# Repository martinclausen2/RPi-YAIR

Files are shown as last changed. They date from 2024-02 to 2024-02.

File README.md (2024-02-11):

# RPi-YAIR
Raspberry Pi YAIR (Yet Another Internet Radio)

Diverted from [Raspberry Pi YAIR - Yet Another Internet Radio](https://www.mikrocontroller.net/articles/Raspberry_Pi_YAIR_(Yet_Another_Internet_Radio) )

German parts to be translated later. Details on one particular hardware setup to be found under articel cited above.

### Einleitung

Ja, es gibt sie: Internetradios. Zum Kaufen. Zum Selbst bauen. Aus Routern. Aus dem Raspberry Pi. Aber schlussendlich gefiel mir keines so gut, dass es mich vom Selbstbau abgehalten hätte ...
### Features für den Nutzer

* Intuitive Bedienung über zwei Drehencoder mit Tastfunktion
  * Dynamische Schrittweitenanpassung für die schnelle und genaue Einstellung der Lautstärke und Sender
* Fernbedienbar via IR-Fernbedieung oder Netzwerk / WLAN via Smartphone
* Sehr niedriger Standby-Stromverbrauch
* Lesen der Musik via Netzwerk oder empfang via BT

### Hardware Setup

* Basis Raspberry Pi Zero (nur headless) oder besser, 512MB, WLAN und BT
* I2S Audio DAC connection please see [External-Non-USB-Audio-DAC-ES9023,-PCM5102,-etc.](https://github.com/MiczFlor/RPi-Jukebox-RFID/wiki/External-Non-USB-Audio-DAC-ES9023,-PCM5102,-etc.)
* Microcontroller connnection please see [Raspberry Pi YAIR - Yet Another Internet Radio](https://www.mikrocontroller.net/articles/Raspberry_Pi_YAIR_(Yet_Another_Internet_Radio) )

## MCU

Die Software besteht aus folgenden Teilen:

* Hauptschleife
  * Setzt Zustände der State-Machines in Befehle, die über den UART gesendet werden, um
  * Steuert die Stromversorgung von Raspberry Pi, Monitor und Audio-Verstärker

* Interrupt-Routinen
  * RC5 Decoder, ausgelöst durch Timer 0 bei 4,5kHz, jeden 9. Aufruf wird auch der Drehencoder ausgewertet
  * Einlesen der Tasten, ausgelöst durch Timer aus RTC der MCU bei 10Hz

* Initialisierung der MCU
  * Core Funktionen, hauptsächliche Stromsparfunktionen
  * I/O Pins
  * Interne RTC als 10Hz Taktgeber: 6*10^6/4/128/10
  * UART: 57600 Bit/s Mode 1
  * Watchdog wird abgeschaltet
  * Interrupts freischalten

* Auswertung Drehencoder

* RC5 Decoder

Der RC5 Decoder beruht auf einer State-Machine, die schrittweise die einzelnen Bits erkennt und dann in Adresse und Daten zerlegt. Nach der Erkennung eines kompletten Kommandos wird steht rCounter auf dem Wert 12 und das Hauptprogramm beginnt mit der Decodierung (Aufruf "DecodeRemote()").

Die Software kann per #define in Quellcode für LPC922 oder LPC93X kompiliert werden. Die zusätzlichen Funktionsblöcke der LPC93X werden nicht verwendet. Als Kompiler ist SDCC zu verwenden.

Bei Bedarf könnte ich MCUs programmieren. Alternativ ist der Code sicher leicht auf einen AVR, STM32, oder ... zu portieren. 

## Raspberry Pi Setup

### Step by Step Instructions

Please follow the follwoing steps to steup the raspberry pi

* deploy raspberry pi os bookworm on sdcard
* setup the configuration 'sudo raspi-config'
  * setup system options
    * WLAN
    * Hostname
  * Interface
    * SSH
    * Serail Port - enable serial port, but not (!) console
  * Localisation Options
    * Timezone
    * Keyboard
    * WLAN Country
  * Advanced Options
    * Expand Filesystem
* update repos `sudo apt-get update`
* update software `sudo apt-get dist-upgrade`
* install software `sudo apt-get install mpd mpc wakeonlan git`
* Reboot Rpi
* Adjust configuration files from RPi folder and changes dummy credentials, consider to modifiy the following files on your traget system in case your installation has other specifics.  
  * `/boot/firmware/cmdline.txt`
    * remove `console=tty1`
  * `/boot/firmware/config.txt`
    * remove `dtparam=audio=on` by addin a hash in fromt of the line
    * add `dtoverlay=hifiberry-dac`
  * If you decide to adjust the start volue, you need to do it in `receiver.c`, complie again, and in `startmpd.sh`
* Copy adjusted configuration files to RPi
* Install BT audio receiver
  * `git clone https://github.com/nicokaiser/rpi-audio-receiver.git`
  * `cd rpi-audio-receiver`
  * Choose the features as needed when running `./install.sh`
* create folder to mount music folder from NAS
  * `mkdir /media/music`
  * `chmod 555 /media/music`
* Make playlist folder accessable `sudo chmod 777 /var/lib/mpd/playlists`
  * Deploy there at least `radio.m3u`, this is used for playback at startup (entry 4)
* stop automated concole activation
  * details may depend on your sprecific RPi model and configuration
	* use `systemctl status` to check for any serial-getty services running and deactivte them using stop, disable, mask
  * `sudo systemctl stop serial-getty@ttyAMA0.service`
  * `sudo systemctl disable serial-getty@ttyAMA0.service`
  * `sudo systemctl mask serial-getty@ttyAMA0.service`
  * `sudo systemctl stop serial-getty@tty1.service`
  * `sudo systemctl disable serial-getty@tty1.service`
  * `sudo systemctl mask serial-getty@tty1.service`
  * `sudo systemctl stop serial-getty@ttyS0.service`
  * `sudo systemctl disable serial-getty@ttyS0.service`
  * `sudo systemctl mask serial-getty@ttyS0.service`
* Activate services
  * `sudo systemctl enable mpd`
  * `sudo systemctl enable wol`
  * `sudo systemctl enable startmpd`
  * `sudo systemctl enable receiver`
  * `sudo systemctl daemon-reload`
* Compile software to receive data from MCU
  * `gcc receiver.c -o receiver`
  * `chmod 755 receiver`
  * If you test the software on console, make sure to delete temp file in `/tmp/mpdlist` before tring to start the service
### Debugging
* Review audio interfaces by
  * `cat /proc/asound/modules`
  * `cat /proc/asound/cards`
* Review service status
  * `systemctl status`
  * `systemctl [status servicename]`
* Review system logs
  * `journalctl -rm -n 1000`
* Inspect data from MCU
  * install minicom `sudo apt-get install minicom`
  * `mincom --device /dev/tytyS0 --baudrate 57600`

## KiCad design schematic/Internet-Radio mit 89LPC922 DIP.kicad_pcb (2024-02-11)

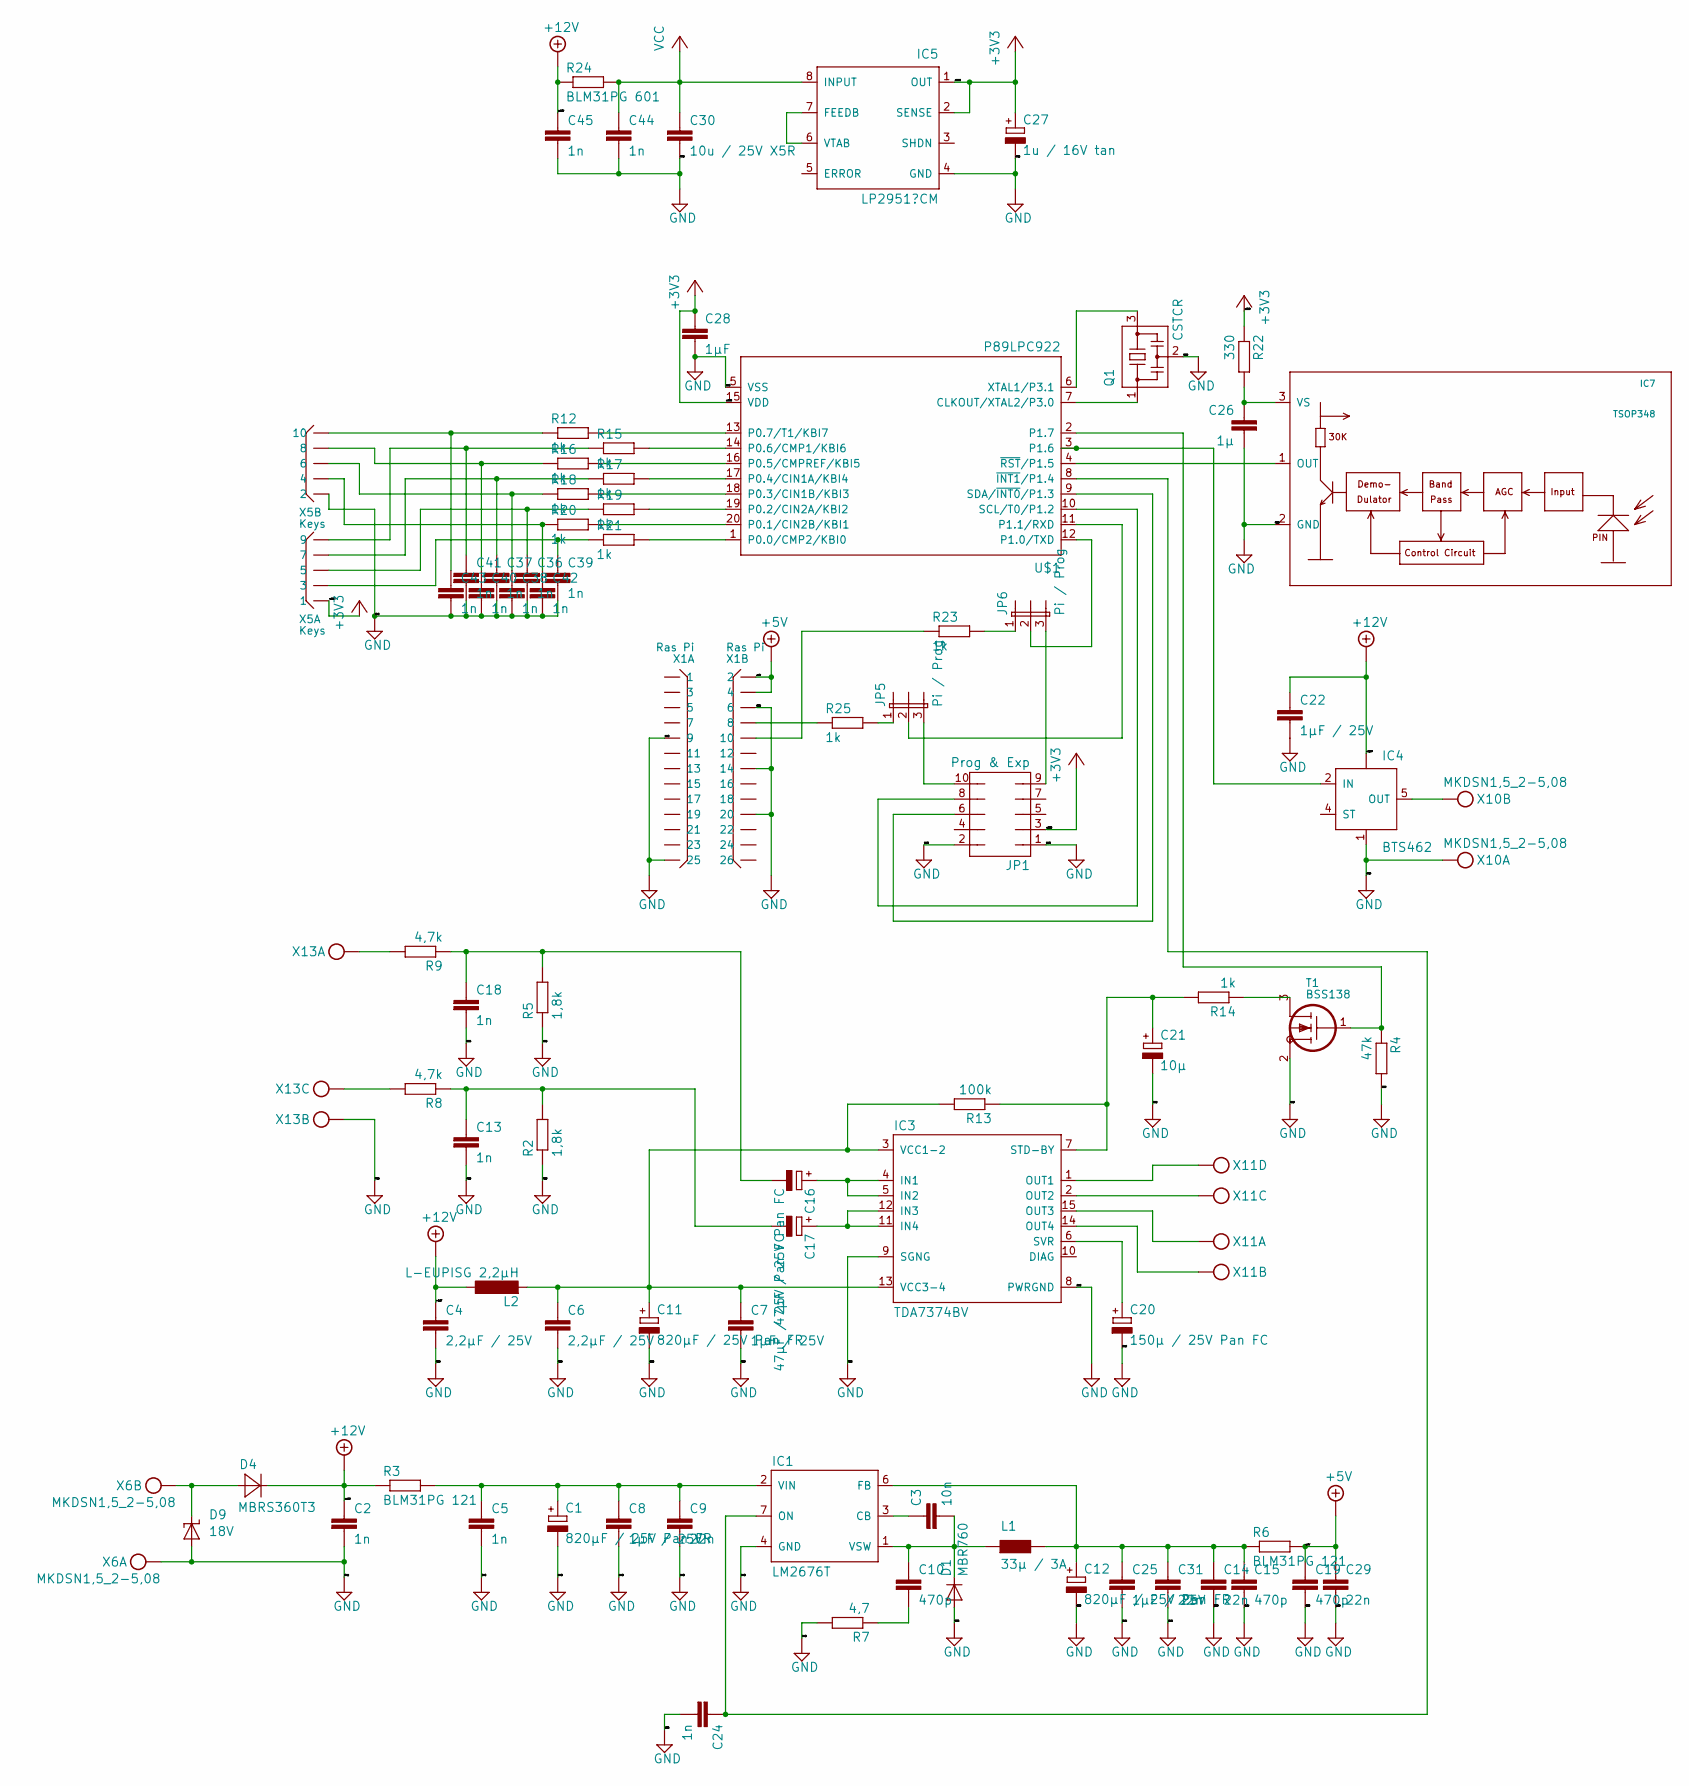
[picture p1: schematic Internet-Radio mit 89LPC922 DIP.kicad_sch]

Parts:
C1, C11, C12: 820µF / 25V Pan FR; TT5D10
C2, C5, C13, C18, C24, C44, C45: 1n; C0805
C3: 10n; C0805
C4, C6: 2,2µF / 25V; C0805
C7, C8, C22, C25: 1µF / 25V; C0805
C9, C14, C29, C31: 22n; C0805
C10, C15, C19: 470p; C0805
C16, C17: 47µF / 25V Pan FC; E2,5-5
C20: 150µ / 25V Pan FC; E3,5-8
C21: 10µ; E2,5-5
C26: 1µ; C0805
C27: 1u / 16V tan; CT3216
C28: 1µF; C0805
C30: 10u / 25V X5R; C1206
C36, C37, C38, C39, C40, C41, C42, C43: 1n; C0603
D1: MBR760; TO220ACS
D4: MBRS360T3; SMC
D9: 18V; SMBJ
IC1: LM2676T; TO220-7
IC3: TDA7374BV; MULTIWATT-15V
IC4: BTS462; TO252-5-11
IC5: LP2951?CM; SO-08
IC7: TSOP348
JP1: Prog & Exp; JP5Q
JP5, JP6: Pi / Prog; JP2
L1: 33µ / 3A; PIS4728
L2: L-EUPISG 2,2µH; PISG
Q1: CSTCR; CSTCR6M
R2, R5: 1,8k; R1206
R3, R6: BLM31PG 121; R1206
R4: 47k; R1206
R7: 4,7; R1206
R8, R9: 4,7k; R1206
R12, R14, R15, R16, R17, R18, R19, R20, R21, R23, R25: 1k; R1206
R13: 100k; R1206
R22: 330; R1206
R24: BLM31PG 601; R1206
T1: BSS138; SOT23
U$1: P89LPC922; DIL20
X1: Ras Pi; X26N-IDC
X5: Keys; X10N-IDC
X6: MKDSN1,5_2-5,08
X10: MKDSN1,5_2-5,08; MPN MKDSN 1,5/2-5.08
X11: MKDSN1,5_4-5,08
X13: MKDSN1,5_3-5,08

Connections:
+3V3: C27.+, C28.1, IC5.1 (OUT), IC5.2 (SENSE), JP1.3, R22.1, U$1.15 (VDD), X5.1
+5V: C19.1, C29.1, R6.2, X1.2, X1.4
+12V: C2.1, C4.1, C22.1, C45.1, D4.C, IC4.TAB (VBB), L2.1, R3.1, R24.1
GND: C1.-, C2.2, C4.2, C5.2, C6.2, C7.2, C8.2, C9.2, C11.-, C12.-, C13.2, C14.2, C15.2, C18.2, C19.2, C20.-, C21.-, C22.2, C24.2, C25.2, C26.2, C27.-, C28.2, C29.2, C30.2, C31.2, C36.2, C37.2, C38.2, C39.2, C40.2, C41.2, C42.2, C43.2, C44.2, C45.2, D1.A, D9.A, IC1.4 (GND), IC3.8 (PWRGND), IC3.9 (SGNG), IC4.1 (GND), IC5.4 (GND), IC7.2 (GND), JP1.1, JP1.2, Q1.2, R2.1, R4.2, R5.1, R7.2, T1.2 (S), U$1.5 (VSS), X1.6, X1.9, X1.14, X1.20, X1.25, X5.2, X6.1, X10.1, X13.2
unnamed: C1.+, C5.1, C8.1, C9.1, IC1.2 (VIN), R3.2
unnamed: C3.1, IC1.3 (CB)
unnamed: C3.2, C10.1, D1.C, IC1.1 (VSW), L1.P$1
unnamed: C10.2, R7.1
unnamed: C6.1, C7.1, C11.+, IC3.3 (VCC1-2), IC3.13 (VCC3-4), L2.2, R13.2
unnamed: C12.+, C14.1, C15.1, C25.1, C31.1, IC1.6 (FB), L1.P$2, R6.1
unnamed: C13.1, C17.-, R2.2, R8.1
unnamed: C16.+, IC3.4 (IN1), IC3.5 (IN2)
unnamed: C16.-, C18.1, R5.2, R9.1
unnamed: C17.+, IC3.11 (IN4), IC3.12 (IN3)
unnamed: C20.+, IC3.6 (SVR)
unnamed: C21.+, IC3.7 (STD-BY), R13.1, R14.2
unnamed: C24.1, IC1.7 (ON), U$1.8 (~INT1/P1.4)
unnamed: C26.1, IC7.3 (VS), R22.2
unnamed: C36.1, R19.1, X5.5
unnamed: C37.1, R17.1, X5.7
unnamed: C38.1, R18.1, X5.6
unnamed: C39.1, R21.1, X5.3
unnamed: C40.1, R16.1, X5.8
unnamed: C41.1, R15.1, X5.9
unnamed: C42.1, R20.1, X5.4
unnamed: C43.1, R12.1, X5.10
unnamed: D4.A, D9.C, X6.2
unnamed: IC3.1 (OUT1), X11.4
unnamed: IC3.2 (OUT2), X11.3
unnamed: IC3.14 (OUT4), X11.2
unnamed: IC3.15 (OUT3), X11.1
unnamed: IC4.2 (IN), U$1.3 (P1.6)
unnamed: IC4.5 (OUT), X10.2
unnamed: IC5.6 (VTAB), IC5.7 (FEEDB)
unnamed: IC7.1 (OUT), U$1.4 (~RST/P1.5)
unnamed: JP1.6, U$1.9 (SDA/~INT0/P1.3)
unnamed: JP1.8, U$1.10 (SCL/T0/P1.2)
unnamed: JP1.9, JP6.3
unnamed: JP1.10, JP5.3
unnamed: JP5.1, R25.2
unnamed: JP5.2, U$1.11 (P1.1/RXD)
unnamed: JP6.1, R23.2
unnamed: JP6.2, U$1.12 (P1.0/TXD)
unnamed: Q1.1, U$1.7 (CLKOUT/XTAL2/P3.0)
unnamed: Q1.3, U$1.6 (XTAL1/P3.1)
unnamed: R4.1, T1.1 (G), U$1.2 (P1.7)
unnamed: R8.2, X13.3
unnamed: R9.2, X13.1
unnamed: R12.2, U$1.13 (P0.7/T1/KBI7)
unnamed: R14.1, T1.3 (D)
unnamed: R15.2, U$1.14 (P0.6/CMP1/KBI6)
unnamed: R16.2, U$1.16 (P0.5/CMPREF/KBI5)
unnamed: R17.2, U$1.17 (P0.4/CIN1A/KBI4)
unnamed: R18.2, U$1.18 (P0.3/CIN1B/KBI3)
unnamed: R19.2, U$1.19 (P0.2/CIN2A/KBI2)
unnamed: R20.2, U$1.20 (P0.1/CIN2B/KBI1)
unnamed: R21.2, U$1.1 (P0.0/CMP2/KBI0)
unnamed: R23.1, X1.10
unnamed: R25.1, X1.8
VCC: C30.1, C44.1, IC5.8 (INPUT), R24.2

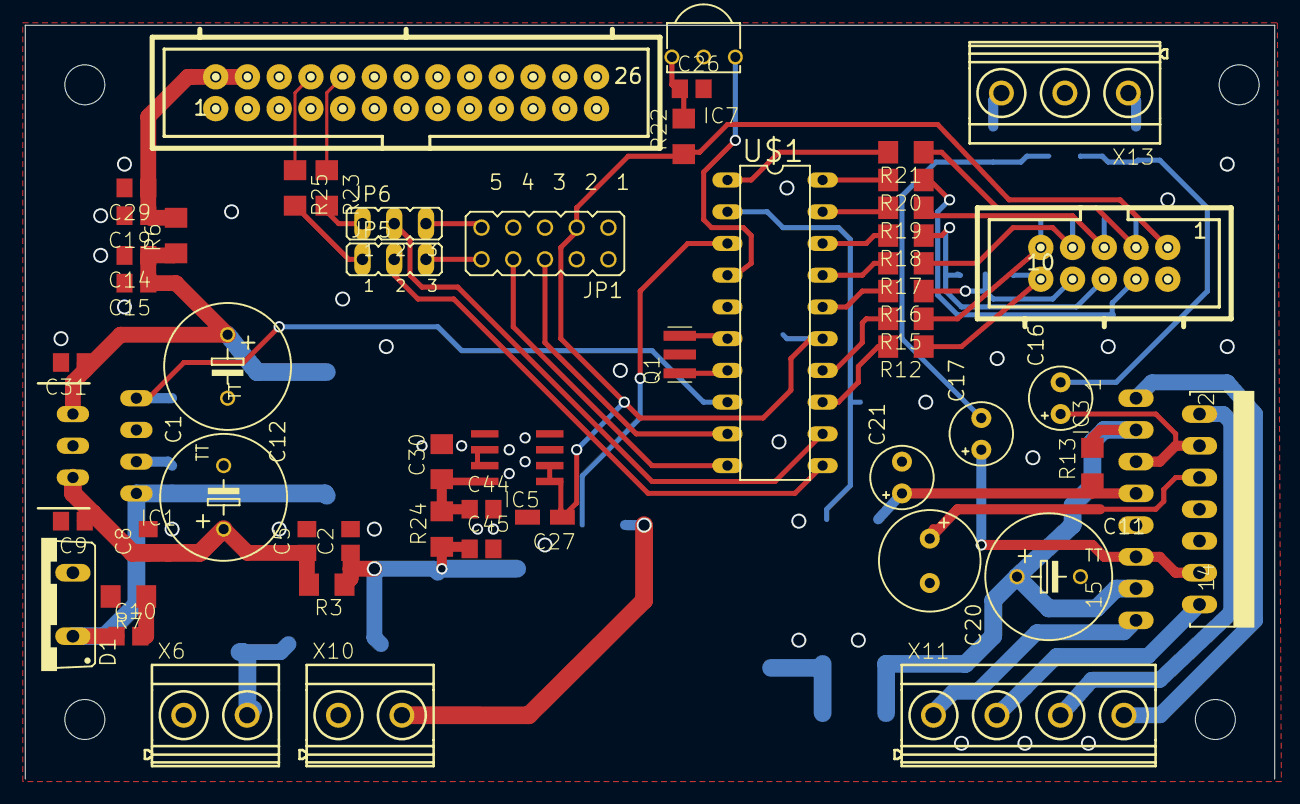
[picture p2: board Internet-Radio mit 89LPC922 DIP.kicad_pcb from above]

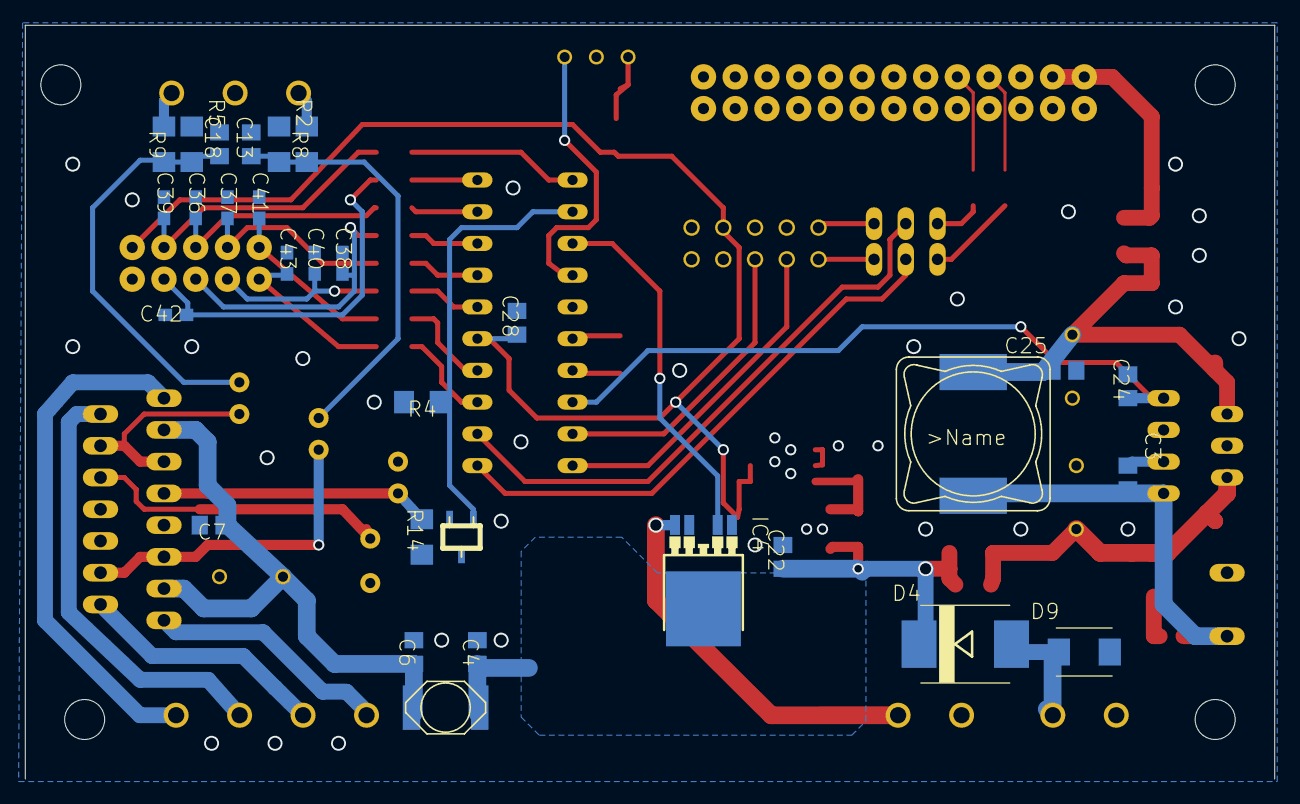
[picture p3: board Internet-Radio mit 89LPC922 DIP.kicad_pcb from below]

Board: 2 copper layers, 100.0 x 60.3 mm, 88 parts (30 on the bottom side), 60 nets.

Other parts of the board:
@HOLE0, @HOLE1, @HOLE2, @HOLE3: (no value)

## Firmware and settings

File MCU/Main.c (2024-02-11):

/**
 * Main Program of a RC5, rotational encoder and keyboard interface
 * @file Main.c
 * use a P89LPC922 or P89LPC93x with 6Mhz resonator or quarz
 * communicates at 57600 bit/s
 * 
 * V1 2014-10-08
 */

#define LPC922

#ifdef LPC922
#include <p89lpc922.h>
#else
#include <p89lpc935_6.h>
#endif
#include <stdio.h>

#define DelayStartup	30
#define DelayShutdown	10

void T0_isr(void) __interrupt (1);		//int from Timer 0 to read RC5 state
void WDT_RTC_isr(void) __interrupt (10);	//int from internal RTC to update PWM read keys

#define isrregisterbank	2		//for all isr on the SAME priority level 

__bit timerFlag;

#include "InitMCU.c"
#include "DualEncoder.c"
#include "ControlPi.c"
#include "RC5.c"
#include "Keys.c"

/** Main loop */
void main()
{
	InitMCU();
	AmpOff=1;
	ToggelPower();
	// Infinite loop
	while(1) {

		if(timerFlag)
		{
			DecodeRemote();

			// A Key was pressed if OldKeyState != 0 and Keystate = 0
			// OldKeyState = 0 must be set by receiving program after decoding as a flag
			if (0 == KeyState)
				{
				switch(OldKeyState)
					{
					case KeyPowerMute:
						if (KeyPressShort > KeyPressDuration)
							{
							if (PiOn) 
								{
								ToggelMute();
								}
							else
								{
								ToggelPower();
								}
							}
						else 
							{
							ToggelPower();
							}
					break;
					case KeyA:
					printf_tiny("KeyA %d\n", KeyPressDuration);
					break;
					case KeyB:
					printf_tiny("KeyB %d\n", KeyPressDuration);
					break;
					case KeyC:
					printf_tiny("KeyC %d\n", KeyPressDuration);
					break;
					}
				OldKeyState=0;
				}

			// A Rotation occured if EncoderSteps!= 0
			// EncoderSteps = 0 must be set by receiving program after decoding
			if (EncoderStepsA)
				{
				printf_tiny("EncA %d\n", EncoderStepsA);
				EncoderStepsA = 0;		//ack received steps
				}
			if (EncoderStepsB)
				{
				printf_tiny("EncB %d\n", EncoderStepsB);
				EncoderStepsB = 0;		//ack received steps
				}
		}
		PCON=0b00000001;				//go idel, wake up by any int
	}
}

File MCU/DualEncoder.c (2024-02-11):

/** Int routine for TWO rotational encoder
 * V0 2013-01-15

 * The calling frequency should not be to low, because otherwise the
 * state machine will be the confused by contact bouncing
 * adding RC-filter may help to keep the calling frequency down

 * duplicated everything to save stack space and increase execution speed

 * A Rotation occured if 0!=EncoderSteps
 * EncoderSteps = 0 must be set by receiving program after decoding
 * Example
// if (EncoderSteps)
// {
// 	LCD_ClearDisplay();
//	printf_tiny("Encoder %d",  EncoderSteps);
//	EncoderSteps=0;
// }
*/

// Encoder and Keys should not overlap in their bits
#define EncoderPort	P0		//select port with encoder
#define SelEncoder 	0b00000011	//select Encoder bits, must be two lower bits
#define SelEncoderState	0b00011100	//select Enocder state bits
#define KeyIncr		0b00000001
#define KeyDecr		0b00000010
#define ShiftEncoderAccel	0x01		//max 7, depends on caling frequency of encoder decode function and required acceleration
#define SelEncoderAccel	0x7F		//depends of ShiftEncoderAccel
#define maxEncoderSteps	100		//avoid overflow
#define minEncoderSteps	-100
#define EncoderAccelStep	0x01		//depends on caling frequency of encoder decode function and required acceleration
#define maxEncoderAccel    0xFF
#define startEncoderDecay	0xAF		//start value for decrementing accelleration, depends on calling frequency

/** State Machine table for rotational encoder
   Format: IN  ACC.0 inc
              ACC.1 dec
              ACC.2 oldstate
              ACC.3 oldstate
              ACC.4 oldstate
          OUT ACC.0 inc, low active!
              ACC.1 dec, low active!
              ACC.2 state
              ACC.3 state
              ACC.4 state
*/

__code unsigned char tblEncoder[] = {
	0b00000011, 0b00000111, 0b00010011, 0b00000011,
	0b00001011, 0b00000111, 0b00000011, 0b00000011,
	0b00001011, 0b00000111, 0b00001111, 0b00000011,
	0b00001011, 0b00000011, 0b00001111, 0b00000001,
	0b00010111, 0b00000011, 0b00010011, 0b00000011,
	0b00010111, 0b00011011, 0b00010011, 0b00000011,
	0b00010111, 0b00011011, 0b00000011, 0b00000010
	};

volatile signed char EncoderStepsA;
volatile signed char EncoderStepsB;

void Encoder()
{
	static unsigned char EncoderStateA;	//stores the encoder state machine A state
 	static unsigned char OldEncoderStateA;
	static unsigned char EncoderAccelA;

	static unsigned char EncoderStateB;	//stores the encoder state machine B state
	static unsigned char OldEncoderStateB;
	static unsigned char EncoderAccelB;

	static unsigned char EncoderDecay;	//common time base


	//construct new state machine input from encoder state and old state
	EncoderStateA &= SelEncoderState;
	EncoderStateA |= (SelEncoder & EncoderPort);
	EncoderStateA = tblEncoder[EncoderStateA];

	//Measure the number of steps, introduce acceleration
	if (KeyIncr == EncoderStateA)
		{
		if ((EncoderStateA == OldEncoderStateA) && (maxEncoderSteps > EncoderStepsA))
			{
			if (maxEncoderAccel > EncoderAccelA)
				{
				EncoderAccelA +=EncoderAccelStep;
				}
			++EncoderStepsA;
			EncoderStepsA += (EncoderAccelA >> ShiftEncoderAccel) & SelEncoderAccel;
			}
		else
			{
			EncoderStepsA = 1;	//change in direction
			OldEncoderStateA = EncoderStateA;
			EncoderAccelA = 0;
			}
		}
	else if (KeyDecr == EncoderStateA)
		{
		if ((EncoderStateA == OldEncoderStateA) && (minEncoderSteps < EncoderStepsA))
			{
			if (maxEncoderAccel > EncoderAccelA)
				{
				EncoderAccelA +=EncoderAccelStep;
				}
			--EncoderStepsA;
			EncoderStepsA -= (EncoderAccelA >> ShiftEncoderAccel) & SelEncoderAccel;
			}
		else
			{
			EncoderStepsA = -1;	//change in direction
			OldEncoderStateA = EncoderStateA;
			EncoderAccelA = 0;
			}
		}

	//construct new state machine input from encoder state and old state
	EncoderStateB &= SelEncoderState;
	EncoderStateB |= (SelEncoder & (EncoderPort>>4));
	EncoderStateB = tblEncoder[EncoderStateB];

	//Measure the number of steps, introduce acceleration
	if (KeyIncr == EncoderStateB)
		{
		if ((EncoderStateB == OldEncoderStateB) && (maxEncoderSteps > EncoderStepsB))
			{
			if (maxEncoderAccel > EncoderAccelB)
				{
				EncoderAccelB +=EncoderAccelStep;
				}
			++EncoderStepsB;
			EncoderStepsB += (EncoderAccelB >> ShiftEncoderAccel) & SelEncoderAccel;
			}
		else
			{
			EncoderStepsB = 1;		//change in direction
			OldEncoderStateB = EncoderStateB;
			EncoderAccelB = 0;
			}
		}
	else if (KeyDecr == EncoderStateB)
		{
		if ((EncoderStateB == OldEncoderStateB) && (minEncoderSteps < EncoderStepsB))
			{
			if (maxEncoderAccel > EncoderAccelB)
				{
				EncoderAccelB +=EncoderAccelStep;
				}
			--EncoderStepsB;
			EncoderStepsB -= (EncoderAccelB >> ShiftEncoderAccel) & SelEncoderAccel;
			}
		else
			{
			EncoderStepsB = -1;	//change in direction
			OldEncoderStateB = EncoderStateB;
			EncoderAccelB = 0;
			}
		}

	if (EncoderDecay)
		{
		--EncoderDecay; 
		}
	else
		{
		EncoderDecay=startEncoderDecay;
		if (EncoderAccelA)
			{
			--EncoderAccelA;			//no new step, decrease acceleration
			}
		if (EncoderAccelB)
			{
			--EncoderAccelB;			//no new step, decrease acceleration
			}
		}

}

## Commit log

2024-02-11 Inital commit
    [config.txt]
2024-02-11 added schematics
    [Internet-Radio mit 89LPC922 DIP.kicad_pcb, Internet-Radio mit 89LPC922 DIP.kicad_sch, Internet-Radio mit 89LPC922 DIP.sch]
2024-02-11 fix sporadic activation of HDMI without connected device
    [config.txt]
